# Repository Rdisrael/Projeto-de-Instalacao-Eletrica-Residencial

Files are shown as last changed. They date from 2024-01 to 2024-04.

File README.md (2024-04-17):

# Resumo

Neste projeto, estou passando pelo desenvolvimento de uma instalação elétrica para a atualização de uma rede antiga. Neste repositório, estão presentes os arquivos do AutoCAD 2D que foram feitos durante o desenvolvimento do projeto, um arquivo do Excel com os cálculos realizados no dimensionamento do sistema, imagens dos diagramas e também um arquivo em PDF que contém um relatório completo do projeto elétrico.

# Diagrama Residencial 



# Diagrama Unifilar 



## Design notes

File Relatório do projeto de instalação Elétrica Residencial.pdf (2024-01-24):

# PROJETO DE INSTALAÇÃO ELÉTRICA RESIDENCIAL

# Israel Rodrigues Dutra

São Paulo
2023

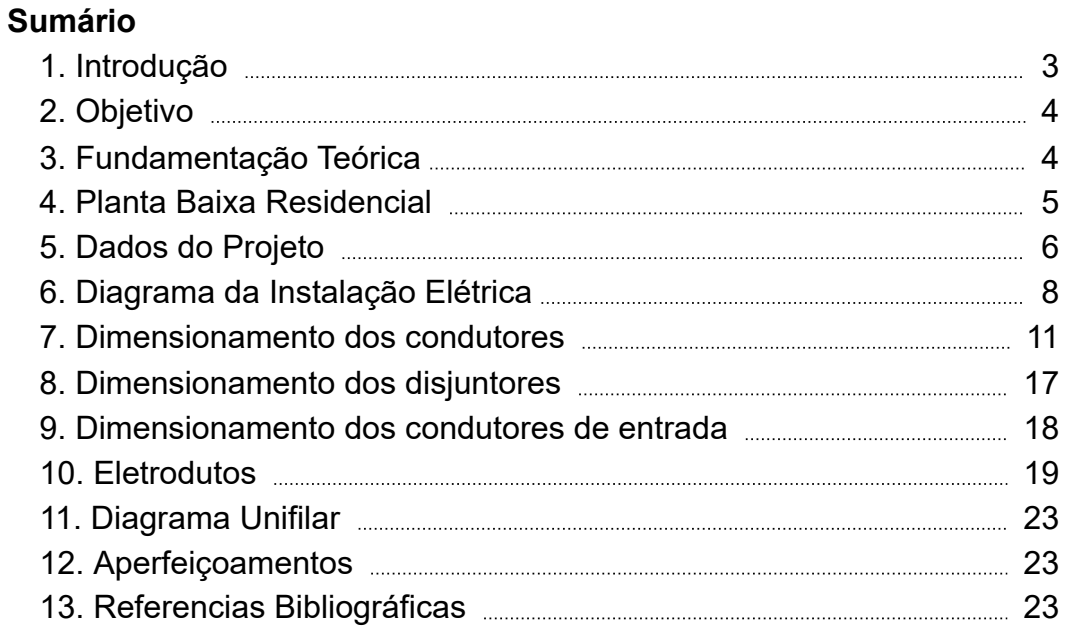
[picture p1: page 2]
Sumário; 1. Introdução; 2. Objetivo; 3. Fundamentação Teórica; 4. Planta Baixa Residencial; 5. Dados do Projeto; 6. Diagrama da Instalação Elétrica; 7. Dimensionamento dos condutores; 8. Dimensionamento dos disjuntores; 9. Dimensionamento dos condutores de entrada; 10. Eletrodutos; 11. Diagrama Unifilar; 12. Aperfeiçoamentos; 13. Referencias Bibliográficas

### 1. Introdução

Muitas vezes é necessário realizar a atualização e a troca das instalações elétricas residenciais. Esse é um projeto real que desenvolvi para um conhecido, trata-se de uma instalação já existente e que possui em sua maioria uma fiação velha, que muitas vezes tem problemas de fornecimento por conta do estado dos circuitos elétricos. Um grande desafio que enfrentei durante o desenvolvimento desse projeto foi que a instalação em questão não se adequá as normas da NBR-5410 e apresenta diversas questões com relação a segurança. Também diminuir ao máximo o preço da instalação foi um grande fator para priorizar a aplicabilidade do projeto foi um grande desafio. O próximo passo é a realização da atualização da instalação, caso o projeto seja aceito pelo dono da instalação.

### 2. Objetivo

Realizar o projeto de uma instalação elétrica já existente visando adequá-la as normas de instalações elétricas vigentes.

### 3. Fundamentação Teórica

Grande parte da fundamentação teórica foi tirada dos materiais de aula das disciplinas de Instalações Elétricas e Laboratório de Instalações Elétricas, esses que por sua vez estão fundamentados na norma NBR-5410. Algumas fontes podem ser encontradas em Referências Bibliográficas.

### 4. Planta Baixa Residencial

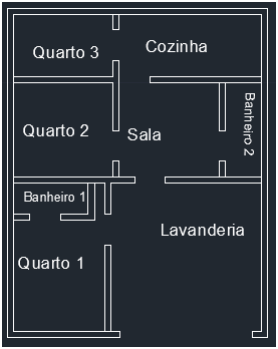
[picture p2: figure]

Figure 1: Planta baixa da residência. Realizado no AutoCAD.

### 5. Dados do Projeto

Dados do Projeto

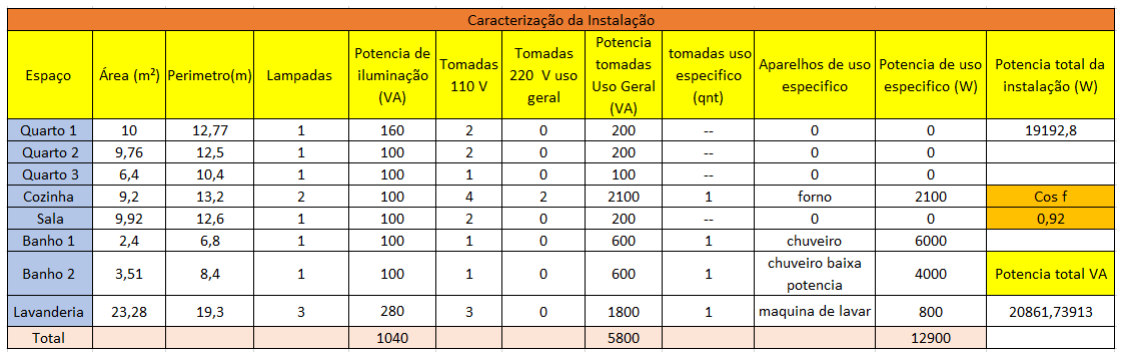
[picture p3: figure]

Figure 2: cos f de 0,92 padrão fornecido pela concessionária elétrica.

Nessa tabela podemos ver os dados sobre a potência de iluminação, tomadas de uso geral, tomadas de uso especifico e potência instalada. Foi usado um chuveiro de baixa potência para o banho 2.
Distribuição dos circuitos

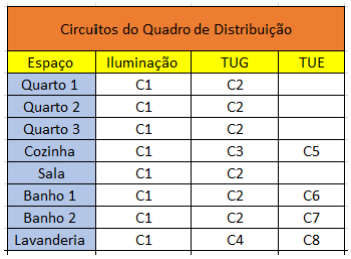
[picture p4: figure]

Figure 3: Distribuição dos circuitos no quadro de distribuição da instalação. São também os disjuntores da instalação.

- C1 é o circuito de iluminação;
- C2 é o circuito de TUG para locais com baixa demanda;
- C3 circuito TUG cozinha;
- C4 circuito TUG lavanderia;
- C5 circuito TUE do forno elétrico;
- C6 circuito TUE do chuveiro;
- C7 circuito TUE do chuveiro de baixa potência;
- C8 circuito TUE da maquina de lavar.

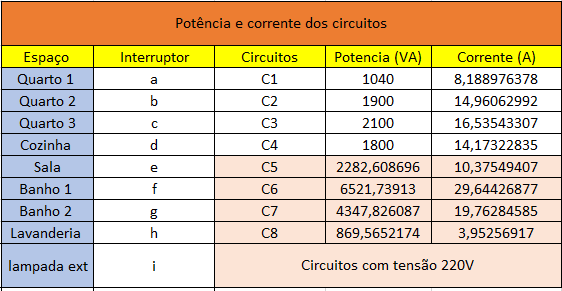
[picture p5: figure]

Figure 4: Potência e corrente dos circuitos. A parte vermelha são os circuitos com tensão 220 V e a parte em branco 127 V. Interruptores na instalação elétrica. Obs: "lampada ext" é a lampada de está na lavanderia correspondente a potência de 80 VA.

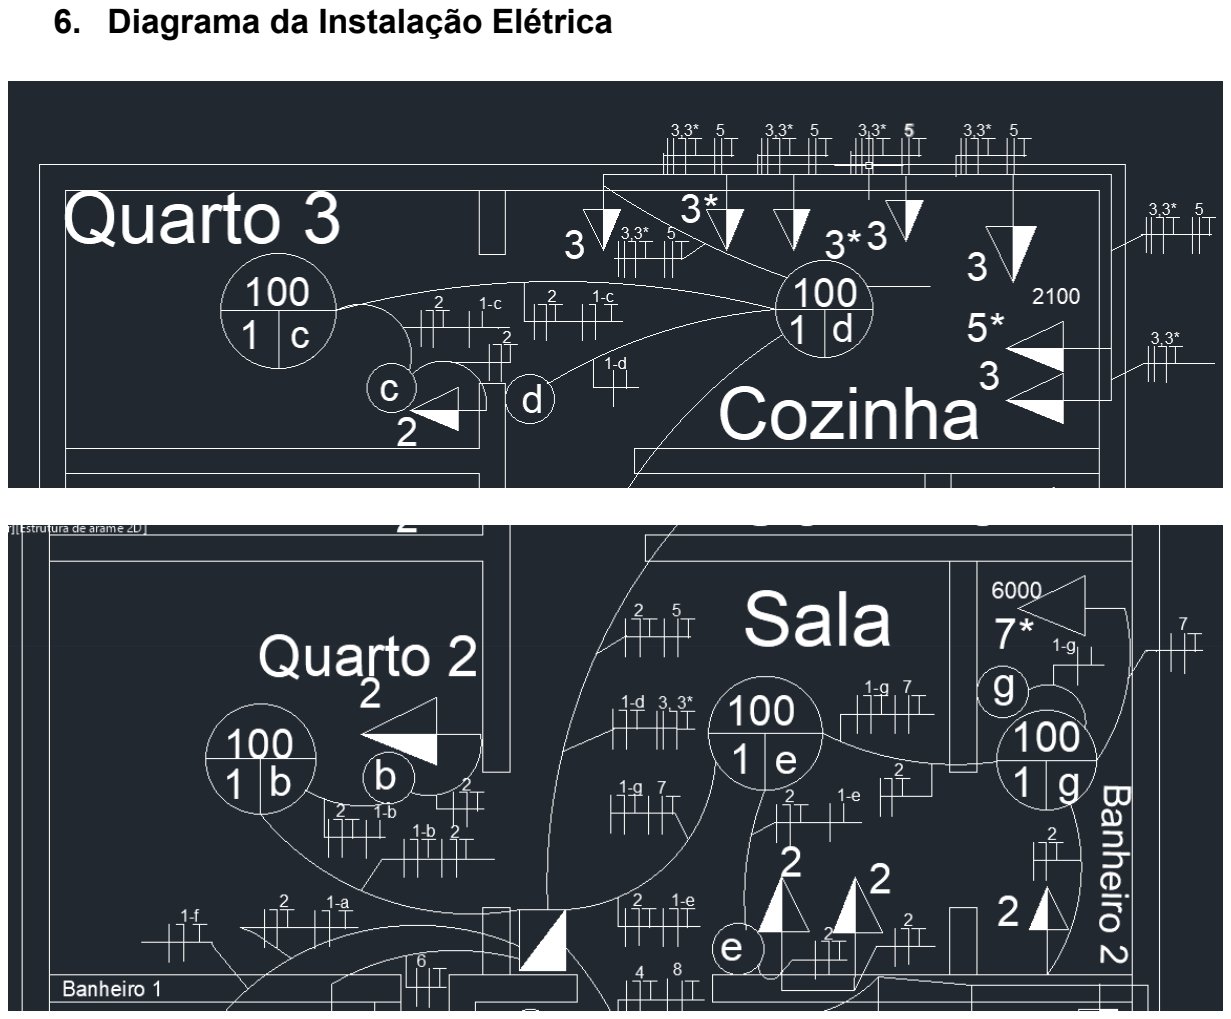
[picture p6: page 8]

### 6. Diagrama da Instalação Elétrica

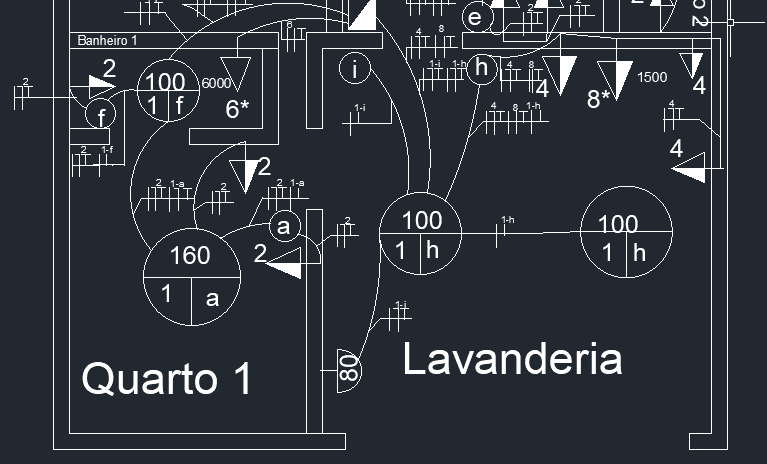
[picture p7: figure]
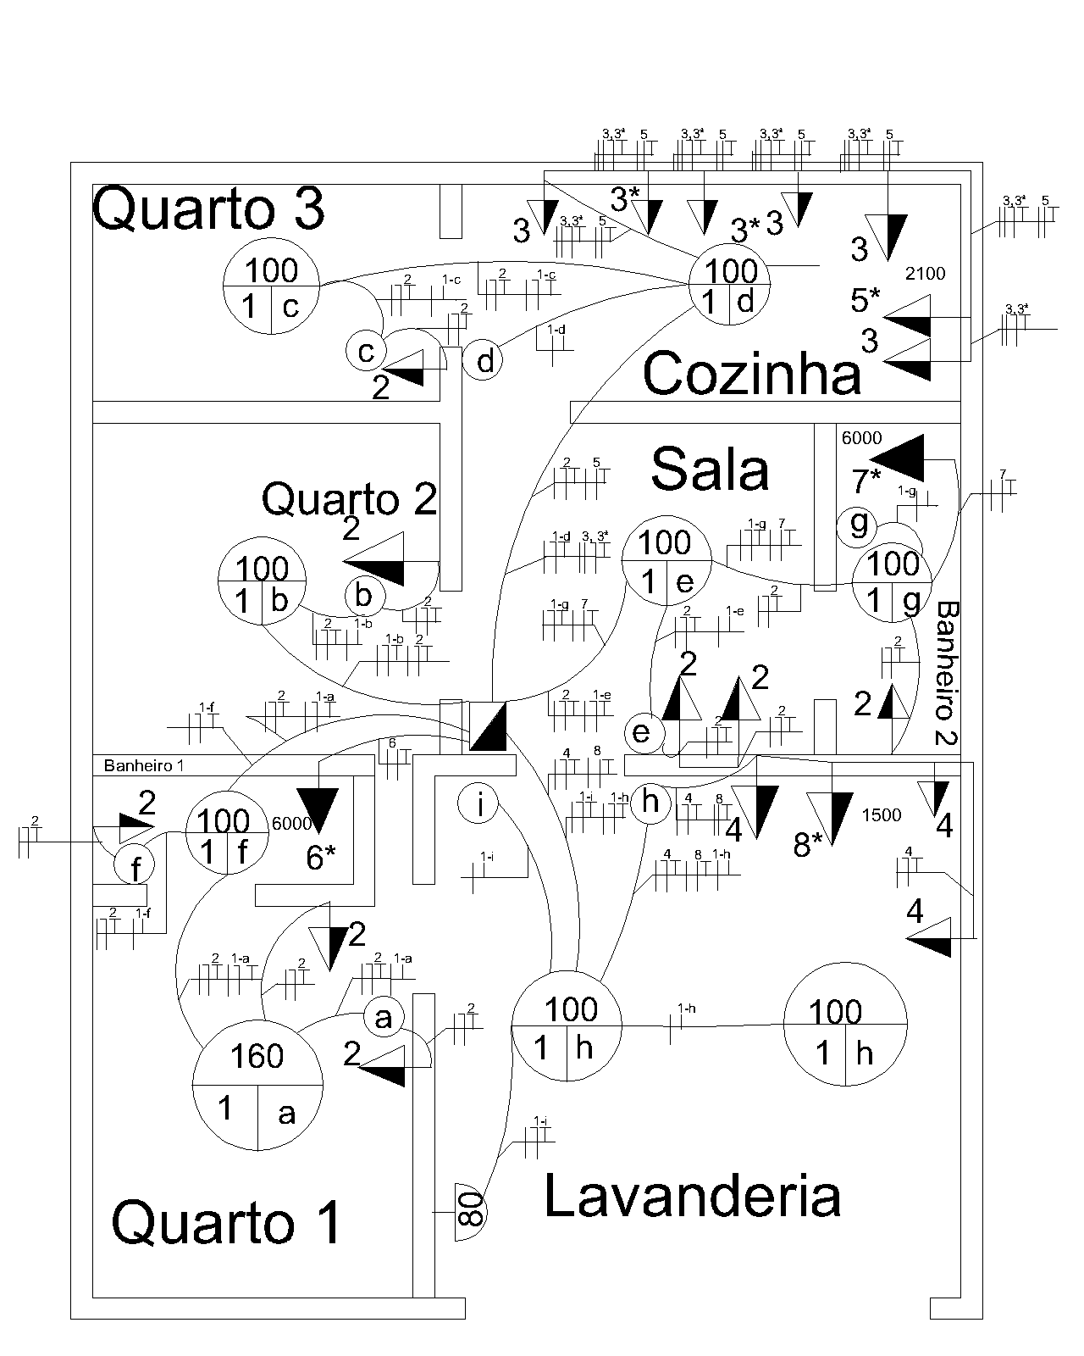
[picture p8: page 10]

### 7. Dimensionamento dos condutores

Realizando os métodos de condução de corrente e fator de agrupamento para determinar a seção dos condutores na instalação. O método de queda de tensão não foi usado, pois a distância da instalação é pequena demais para esse método surtir algum efeito. Foram utilizados o catalogo da Prysmian e a NBR 5410 para realizar os cálculos. No catalogo Prysmian tabela 1 temos:

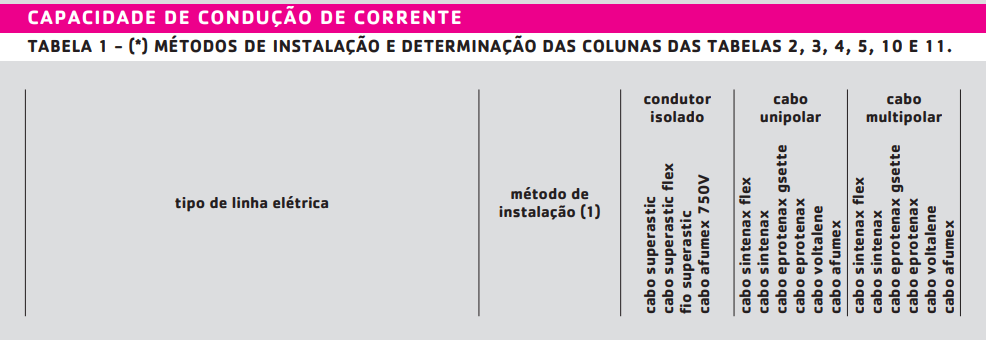
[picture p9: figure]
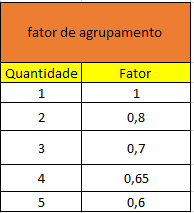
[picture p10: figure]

Figure 5: Tabela de fatores de agrupamento usado nos cálculos.

Foi dimensionado para condutores de cobre com material isolante de PVC. A temperatura de instalação foi de 30°C, pois é maior do que a temperatura media para a cidade de São Paulo. Para toda a instalação foi usado o método de instalação B1.
Os cálculos levarão em conta apenas os eletrodutos que possuem o maior numero de circuitos, pois eles determinarão o valor do fator de agrupamento. Como esses eletrodutos são os principais, por eles passam todos os circuitos da instalação, assim podemos calcular a corrente dos mesmos. São eles:

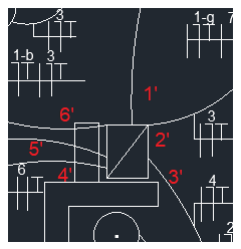
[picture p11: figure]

Figure 6: Nomes dados aos eletrodutos principais.

No eletroduto 1' temos os seguintes circuitos:

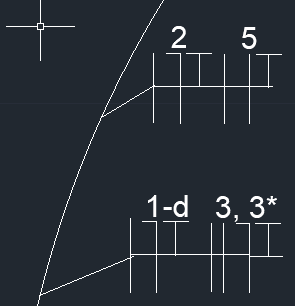
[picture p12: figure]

Figure 7: Eletroduto 1'.

Como o circuito 1-D é um circuito de iluminação ele engloba toda a potência do circuito 1, portanto são 1040 VA. Logo não é necessário realizar o calculo para 1-C, pois será o mesmo circuito mudando apenas o nome do interruptor.

Figure 8: Dimensionamento para o C5. Em laranja são as informações sobre o nome do eletroduto, quantos circuitos estão presentes nesse eletroduto e o circuito do quadro que ele representa.

Figure 9: Dimensionamento para o C3. Em azul está a quantidade de cabos presente nesse circuito.

Figure 10: Dimensionamento para o C4. Em vermelho temos os dados de cálculo.

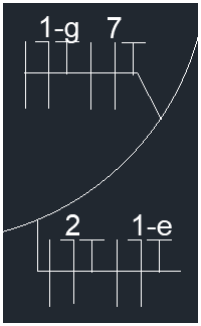
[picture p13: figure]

Figure 11: Eletroduto 2'.

Para o eletroduto 2' temos os tamanho de condutor iguais para os circuitos 1 e 2. O calculo do circuito 7 segue abaixo :

Figure 12: Dimensionamento para o C7.

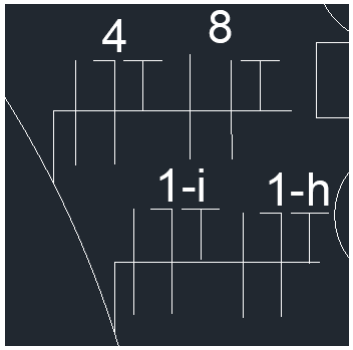
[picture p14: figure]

Figure 13: Eletroduto 3'.

Figure 14: Dimensionamento para o C4.

Figure 15: Dimensionamento para o C8.

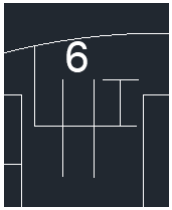
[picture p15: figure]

Figure 16: Eletroduto 4'

Figure 17: Dimensionamento para o C6.

Para os eletrodutos 5' e 6' os tamanhos dos condutores já foram calculados anteriormente.

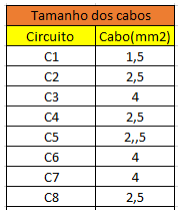
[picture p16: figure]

Figure 18: Tabela de tamanho dos cabos em cada circuito.

### 8. Dimensionamento dos disjuntores

Segundo a NBR 5410 temos dois itens que devem ser seguidos para o dimensionamento dos disjuntores, são eles:

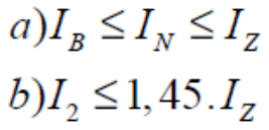
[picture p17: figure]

Figure 19: IB= corrente do circuito, IN= corrente do disjuntor selecionado, IZ=corrente max condutor e I2=IN*1,45.

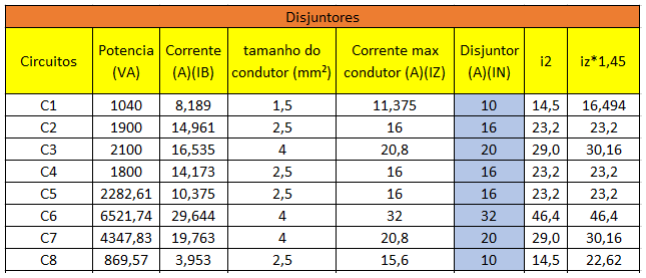
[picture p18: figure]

Figure 20: Tabela do dimensionamento dos disjuntores. A coluna em azul são os disjuntores dimensionados.

### 9. Dimensionamento dos condutores de entrada

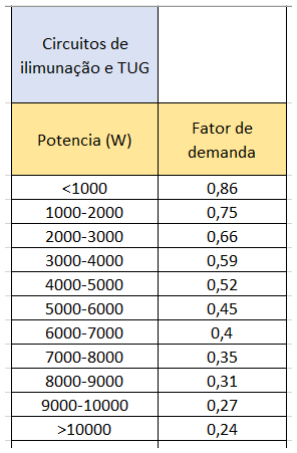
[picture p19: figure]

Figure 21: Tabela de fator de demanda para circuitos TUG e iluminação.

Figure 22: Tabela de fator de demanda de circuitos TUE.

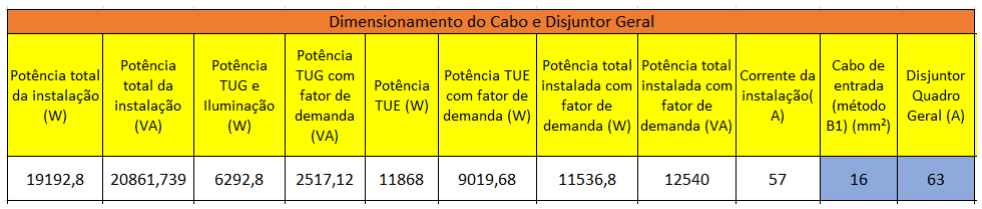
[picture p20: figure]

Figure 23: Dimensionamento de cabo de entrada e disjuntor geral baseado na potência instalada com fator de demanda.

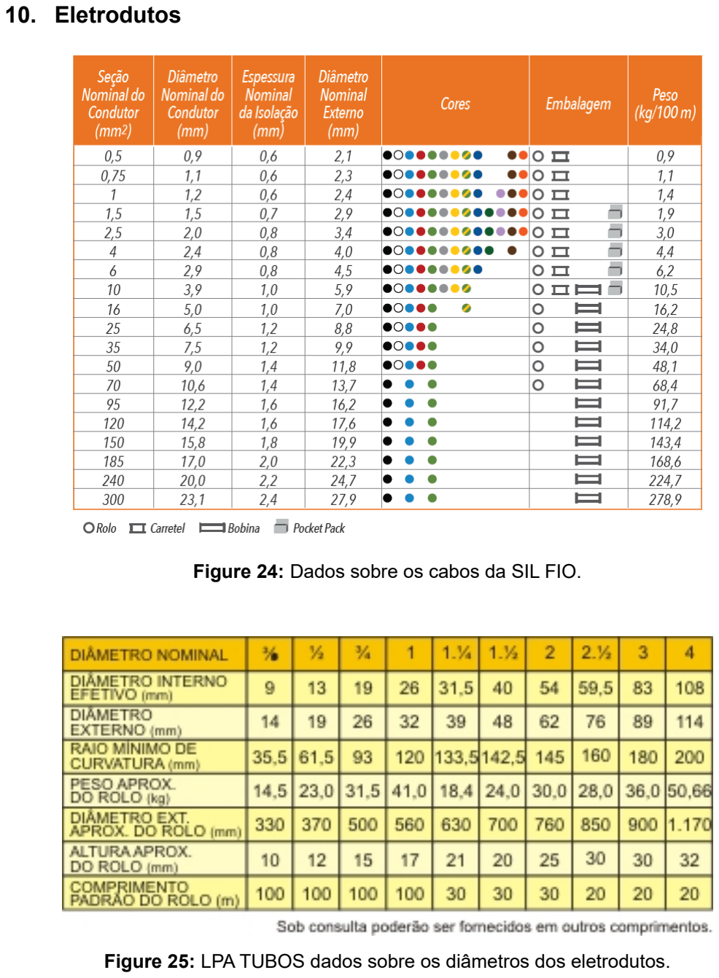
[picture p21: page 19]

### 10. Eletrodutos

Figure 24: Dados sobre os cabos da SIL FIO.

Figure 25: LPA TUBOS dados sobre os diâmetros dos eletrodutos.

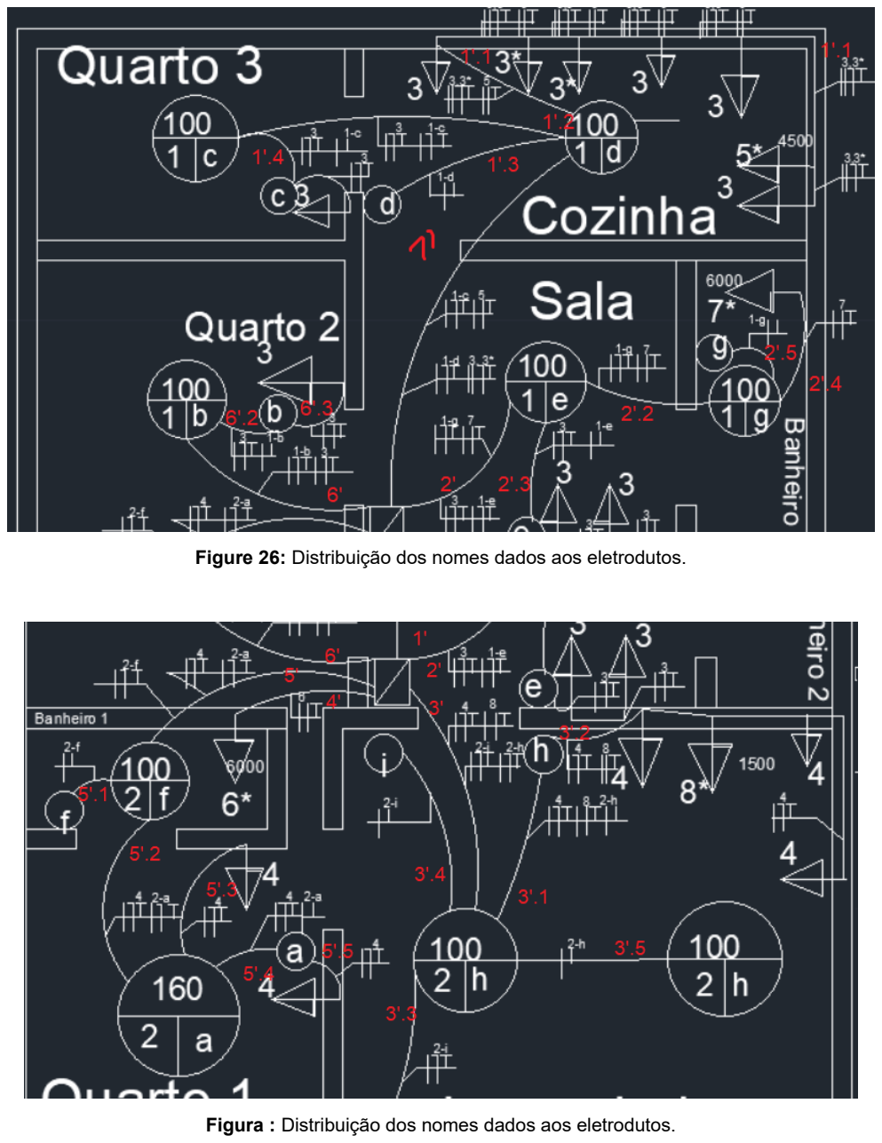
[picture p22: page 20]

Figure 26: Distribuição dos nomes dados aos eletrodutos.

Figura : Distribuição dos nomes dados aos eletrodutos.

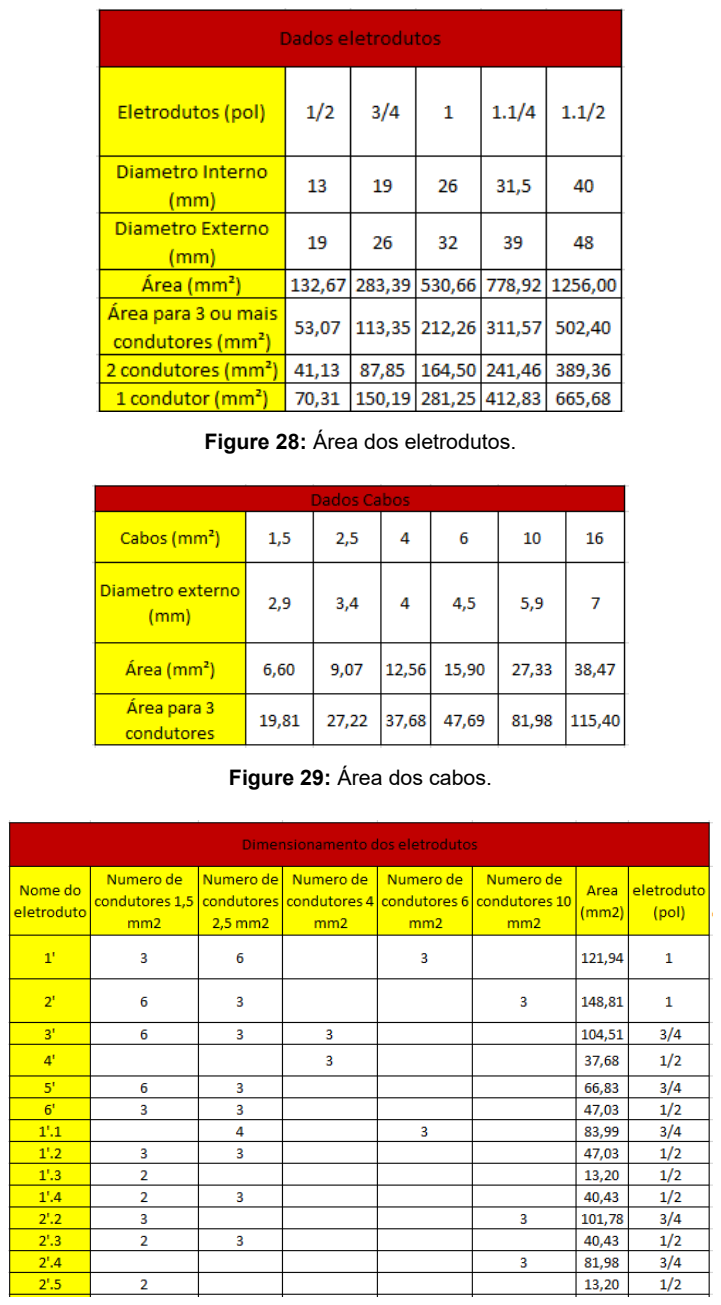
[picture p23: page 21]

Figure 28: Área dos eletrodutos.

Figure 29: Área dos cabos.

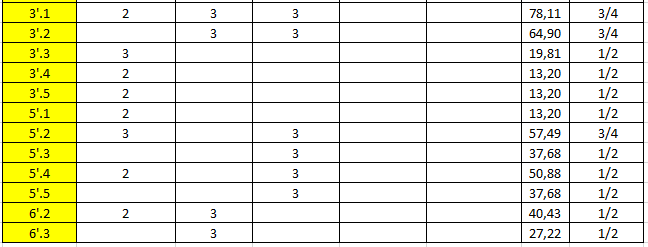
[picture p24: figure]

Figure 30: Tabela de dimensionamento dos eletrodutos.

### 11. Diagrama Unifilar

### 12. Aperfeiçoamentos

Para melhorar o projeto algumas atualizações podem ser realizadas, são elas:
- Dimensionar dispositivos de proteção;
- Quantidade de materiais;
- Preço da instalação;
- Tarifação.

### 13. Referencias Bibliográficas

- https://www.drb-m.org/av1/7-projetodasinstalacoeseletricas.pdf
- http://www.sas.sc.gov.br/images/creas/Projeto_El%C3%A9trico_CREAS-Model.pdf
- https://www.escolatecnicasandrasilva.com.br/pdf/bv_instalacao_residencial_6731dq.pdf

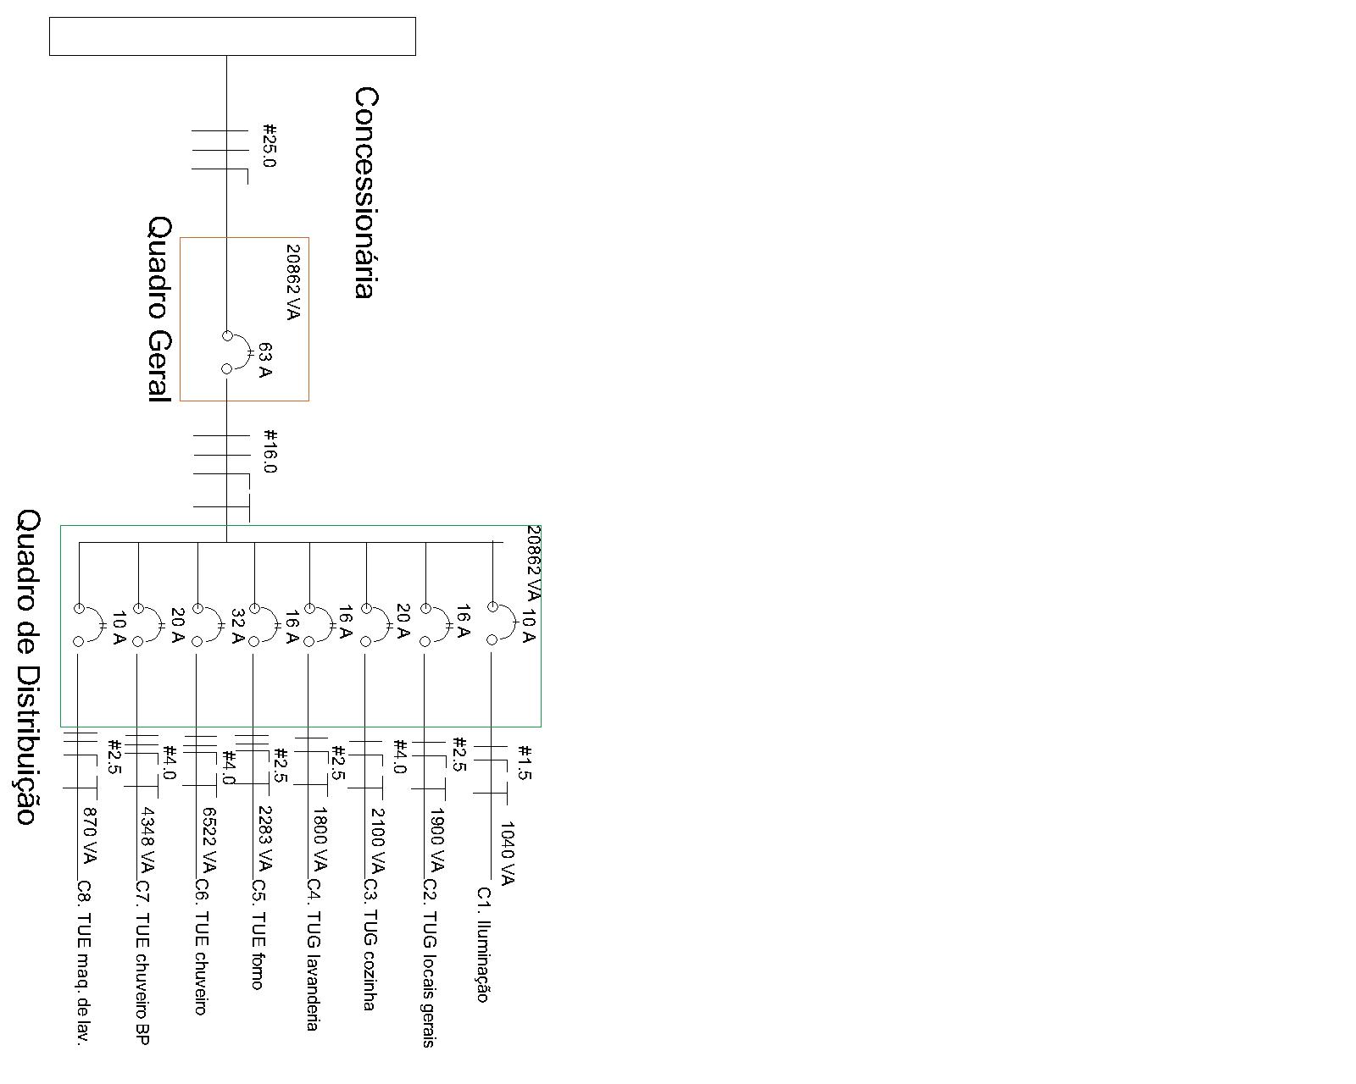
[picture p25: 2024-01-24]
diagramaunifilar.jpg

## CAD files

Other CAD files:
diagramacasa.dwg
